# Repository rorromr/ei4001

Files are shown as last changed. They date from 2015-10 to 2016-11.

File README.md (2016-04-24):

# EI4001

## Torso lift mechanism

## Instalación

# Repositorio

```
git clone https://github.com/rorromr/ei4001.git
cd ei4001
git submodule init
git submodule update
```
# Librerías Arduino

Para la instalación de librerías se crean enlaces simbolicos en el directorio `~/Arduino/libraries/`.

```
cd ei4001/arduino
./install.sh

```

## Comandos Git

[Guía rápida Git](http://rogerdudler.github.io/git-guide/index.es.html)

### Commandos útiles

* Clonar repositorio: `git clone user@ip_server:repo`
* Crear rama: `git checkout -b nueva_rama`
* Listar ramas: `git branch -a`
* Bajar rama: `git pull origin nombre_rama`
* Crear rama local y setear track remoto: `git checkout -t origin/nombre_rama`
* Borrar rama local (-D para forzar): `git branch -d nombre_rama`
* Borrar rama remota: `git push origin :nombre-rama`
* Subir nueva rama con tracking: `git push -u origin rama`
* Actualizar lista de ramas: `git remote update origin --prune`
* Borrar rama local: `git branch -d rama`
* Borrar rama remota: `git push origin --delete rama`

## Markdown

* [Markdown basics](https://help.github.com/articles/markdown-basics/)
* [Mastering Markdown](https://guides.github.com/features/mastering-markdown/)

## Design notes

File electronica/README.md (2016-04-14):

# EI4001

## Torso lift mechanism

Archivos de diseño electrónico.

## Puente H

Puente H basado en MOSFET de potencia IRF2804 usando drivers
IR2110.

## Sitios web

* [Calculo de ancho de pistas](http://www.desmith.net/NMdS/Electronics/TraceWidth.html)
* [Ejemplos puente H](http://tahmidmc.blogspot.cl/2013/01/using-high-low-side-driver-ir2110-with.html)

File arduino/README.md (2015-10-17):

# SerialDXL

Librería para el manejo de dispositivos usando el protoco Dynamixel sobre RS485.
Gestiona la recepción de mensajes y mapeo de memoria (RAM e EEPROM).

# Encoder

Librería para el uso de pines digitales por registro [DigitalIO](https://github.com/greiman/DigitalIO/blob/master/DigitalIO/PinIO.h).

# Instalación

* Se debe instalar el software Arduino en `/opt/ardino`.
* Las librerías de usuario se almacenan en `~/Arduino/libraries`.
* Configurar [Ardunino-Makefile](https://github.com/sudar/Arduino-Makefile) según `setup.sh`.

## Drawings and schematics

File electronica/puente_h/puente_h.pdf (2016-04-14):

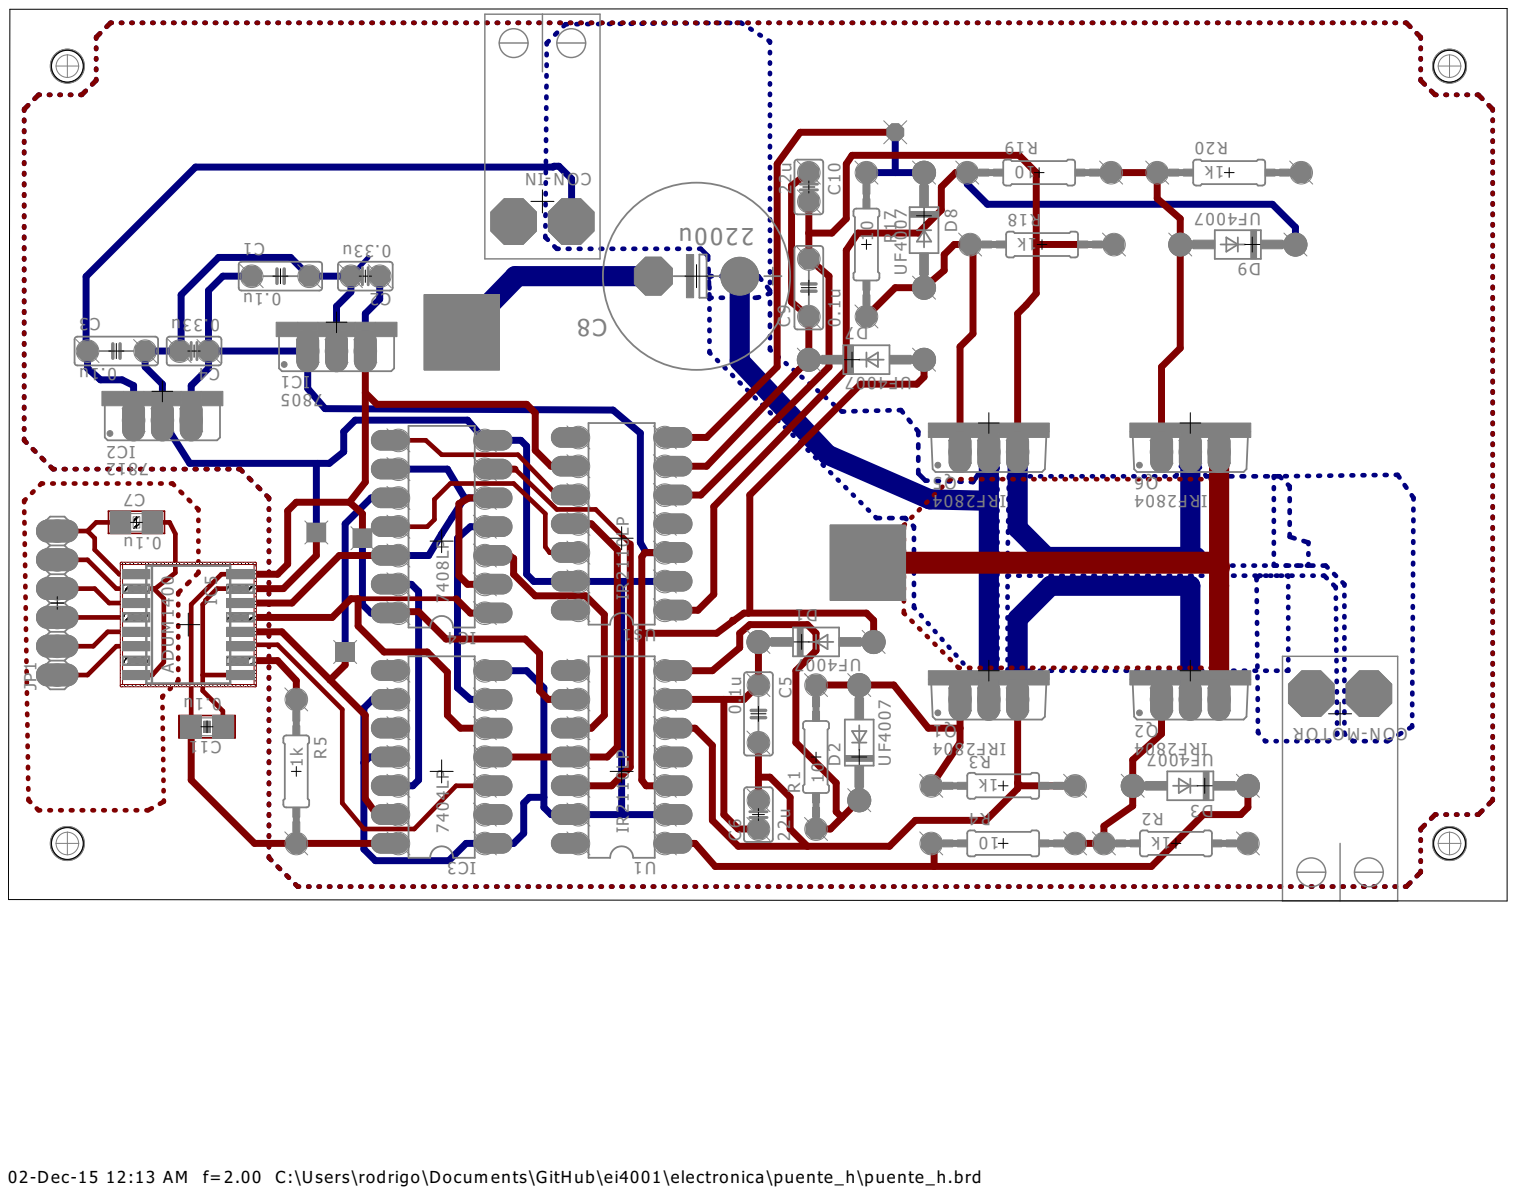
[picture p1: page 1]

02-Dec-15 12:13 AM f=2.00 C:\Users\rodrigo\Documents\GitHub\ei4001\electronica\puente_h\puente_h.brd

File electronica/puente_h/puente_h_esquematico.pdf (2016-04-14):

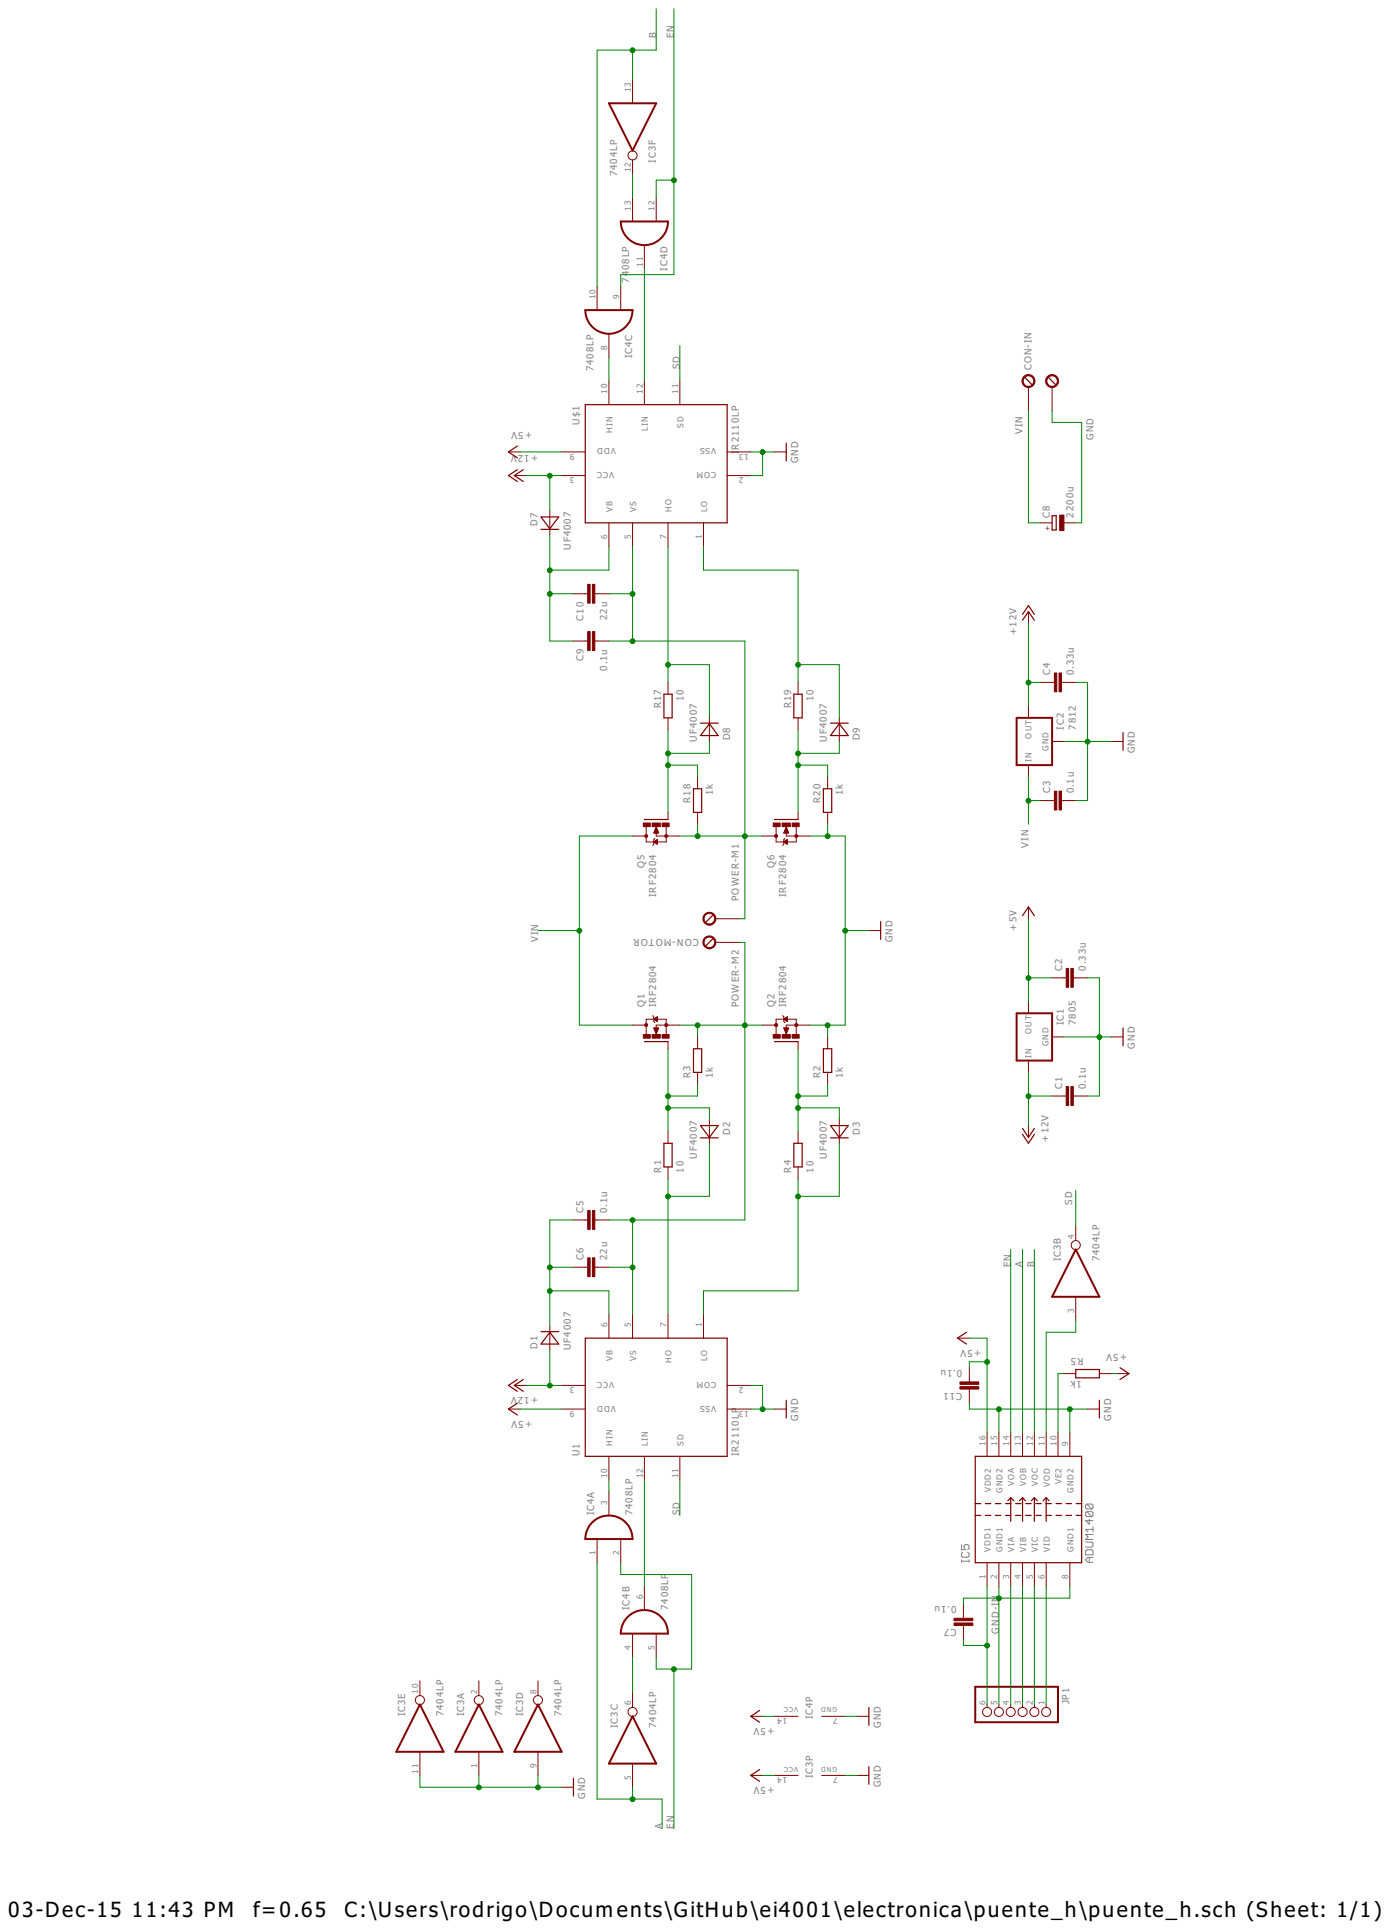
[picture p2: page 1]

03-Dec-15 11:43 PM f=0.65 C:\Users\rodrigo\Documents\GitHub\ei4001\electronica\puente_h\puente_h.sch (Sheet: 1/1)

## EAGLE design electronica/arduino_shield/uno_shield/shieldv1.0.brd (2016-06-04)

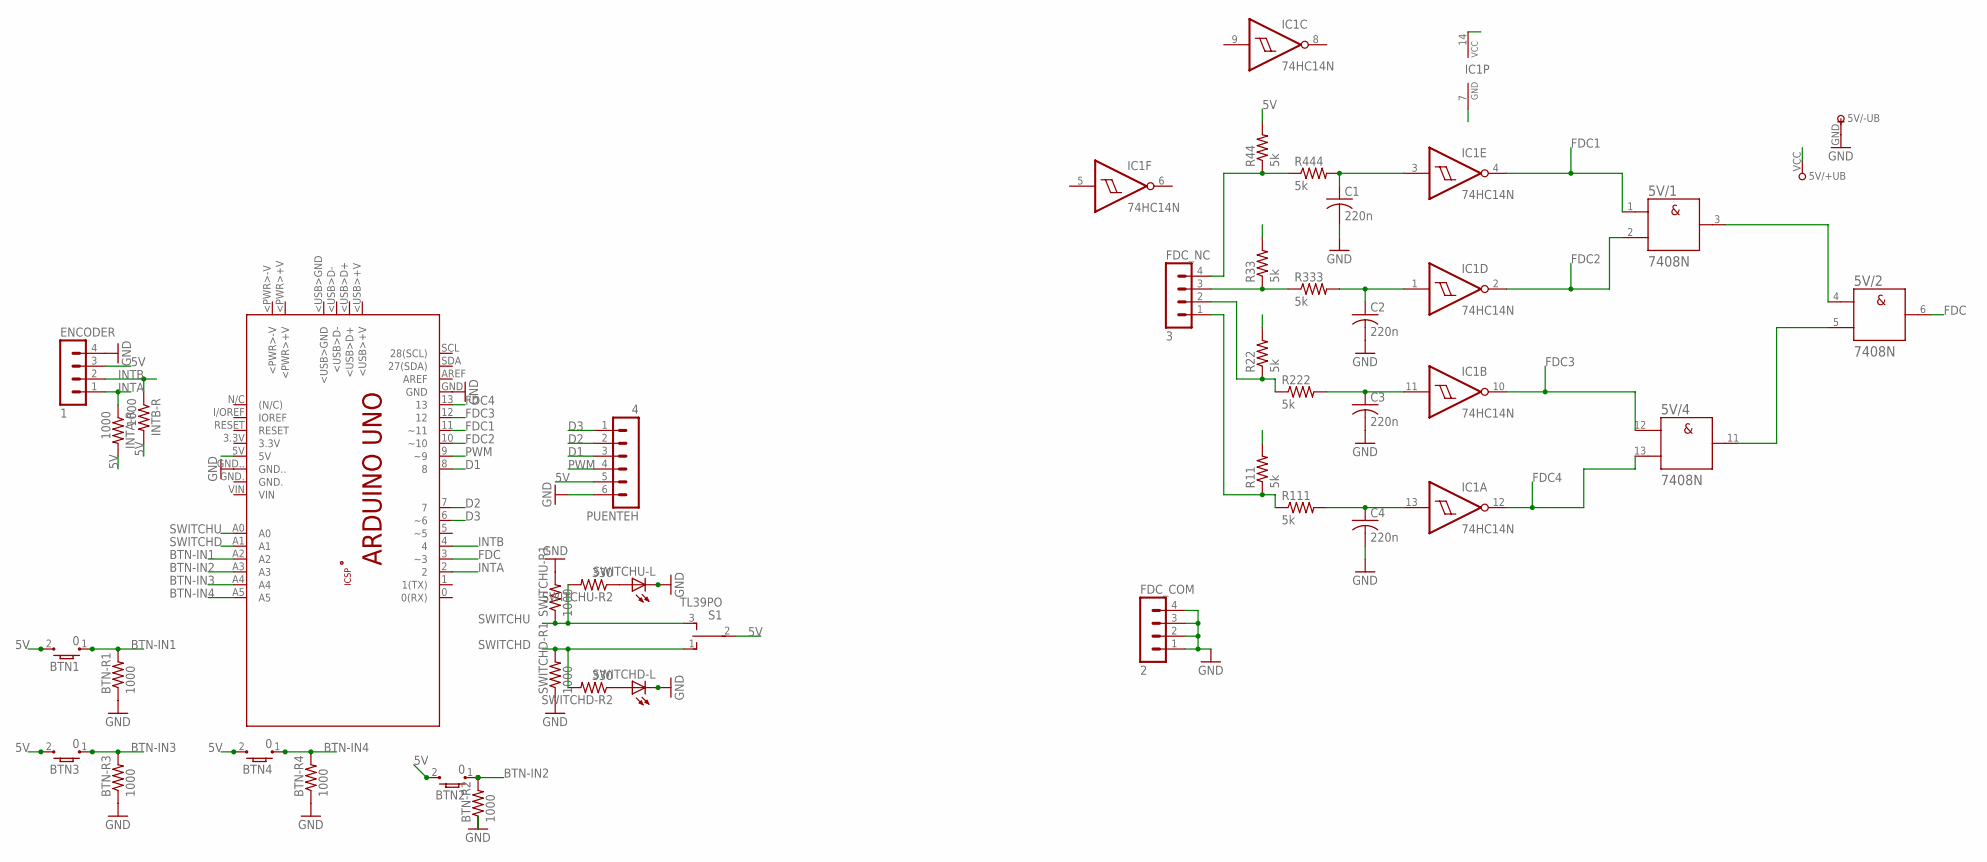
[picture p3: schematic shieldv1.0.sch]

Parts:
5V: 7408N; DIL14
BTN1, BTN2, BTN3, BTN4: 0; TL3303_J
BTN-R1, BTN-R2, BTN-R3, BTN-R4: 1000; 0204/7
C1, C2, C3, C4: 220n; C025-030X050
ENCODER: 1; MA04-1
FDC_COM: 2; MA04-1
FDC_NC: 3; MA04-1
IC1: 74HC14N; DIL14
INTA-R: 1000; 0204/7
INTB-R: 1000; 0204/7
PCB1: ARDUINO_UNO
PUENTEH: 4; MA06-1
R11, R22, R33, R44, R111, R222, R333, R444: 5k; 0204/7
S1: TL39PO; TL3XPO
SWITCHD-L: LED_ELD260; LED_LD260
SWITCHD-R1: 1000; 0204/7
SWITCHD-R2: 330; 0204/7
SWITCHU-L: LED_ELD260; LED_LD260
SWITCHU-R1: 1000; 0204/7
SWITCHU-R2: 330; 0204/7

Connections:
5V: 5V.VCC (+UB), BTN1.2, BTN2.2, BTN3.2, BTN4.2, ENCODER.3, IC1.14 (VCC), INTA-R.2, INTB-R.2, PCB1.5V, PUENTEH.5, R11.2, R22.2, R33.2, R44.2, S1.2
BTN-IN1: BTN1.1, BTN-R1.2, PCB1.A2
BTN-IN2: BTN2.1, BTN-R2.2, PCB1.A3
BTN-IN3: BTN3.1, BTN-R3.2, PCB1.A4
BTN-IN4: BTN4.1, BTN-R4.2, PCB1.A5
D1: PCB1.8, PUENTEH.3
D2: PCB1.7, PUENTEH.2
D3: PCB1.6 (~6), PUENTEH.1
FDC: 5V.6 (Y), PCB1.3 (~3)
FDC1: 5V.1 (A), IC1.4 (O), PCB1.11 (~11)
FDC2: 5V.2 (B), IC1.2 (O), PCB1.10 (~10)
FDC3: 5V.12 (A), IC1.10 (O), PCB1.12
FDC4: 5V.13 (B), IC1.12 (O), PCB1.13
GND: 5V.GND (-UB), BTN-R1.1, BTN-R2.1, BTN-R3.1, BTN-R4.1, C1.2, C2.2, C3.2, C4.2, ENCODER.4, FDC_COM.1, FDC_COM.2, FDC_COM.3, FDC_COM.4, IC1.7 (GND), PCB1.GND, PCB1.GND.., PUENTEH.6, SWITCHD-L.K (C), SWITCHD-R1.1, SWITCHU-L.K (C), SWITCHU-R1.2
INTA: ENCODER.1, INTA-R.1, PCB1.2
INTB: ENCODER.2, INTB-R.1, PCB1.4
unnamed: FDC_NC.3, R33.1, R333.1
unnamed: SWITCHU-L.A, SWITCHU-R2.1
unnamed: SWITCHD-L.A, SWITCHD-R2.1
unnamed: FDC_NC.4, R44.1, R444.1
unnamed: C1.1, IC1.3 (I), R444.2
unnamed: C2.1, IC1.1 (I), R333.2
unnamed: FDC_NC.2, R22.1, R222.1
unnamed: C3.1, IC1.11 (I), R222.2
unnamed: FDC_NC.1, R11.1, R111.1
unnamed: C4.1, IC1.13 (I), R111.2
unnamed: 5V.5 (B), 5V.11 (Y)
unnamed: 5V.3 (Y), 5V.4 (A)
PWM: PCB1.9 (~9), PUENTEH.4
SWITCHD: PCB1.A1, S1.1 (O), SWITCHD-R1.2, SWITCHD-R2.2
SWITCHU: PCB1.A0, S1.3 (S), SWITCHU-R1.1, SWITCHU-R2.2

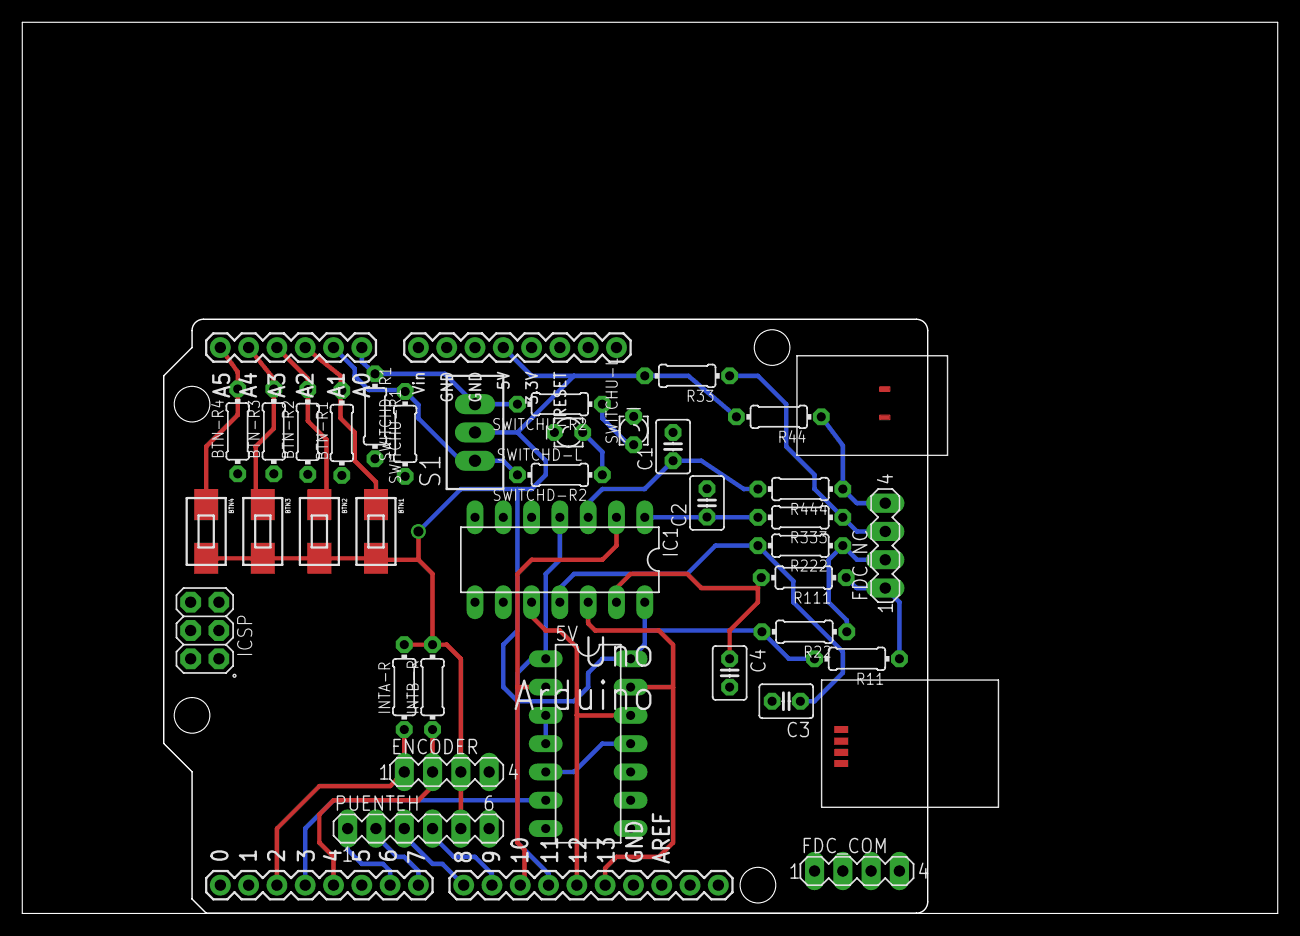
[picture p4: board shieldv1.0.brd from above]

Board: 2 copper layers, 112.7 x 80.0 mm, 36 parts (0 on the bottom side), 31 nets.

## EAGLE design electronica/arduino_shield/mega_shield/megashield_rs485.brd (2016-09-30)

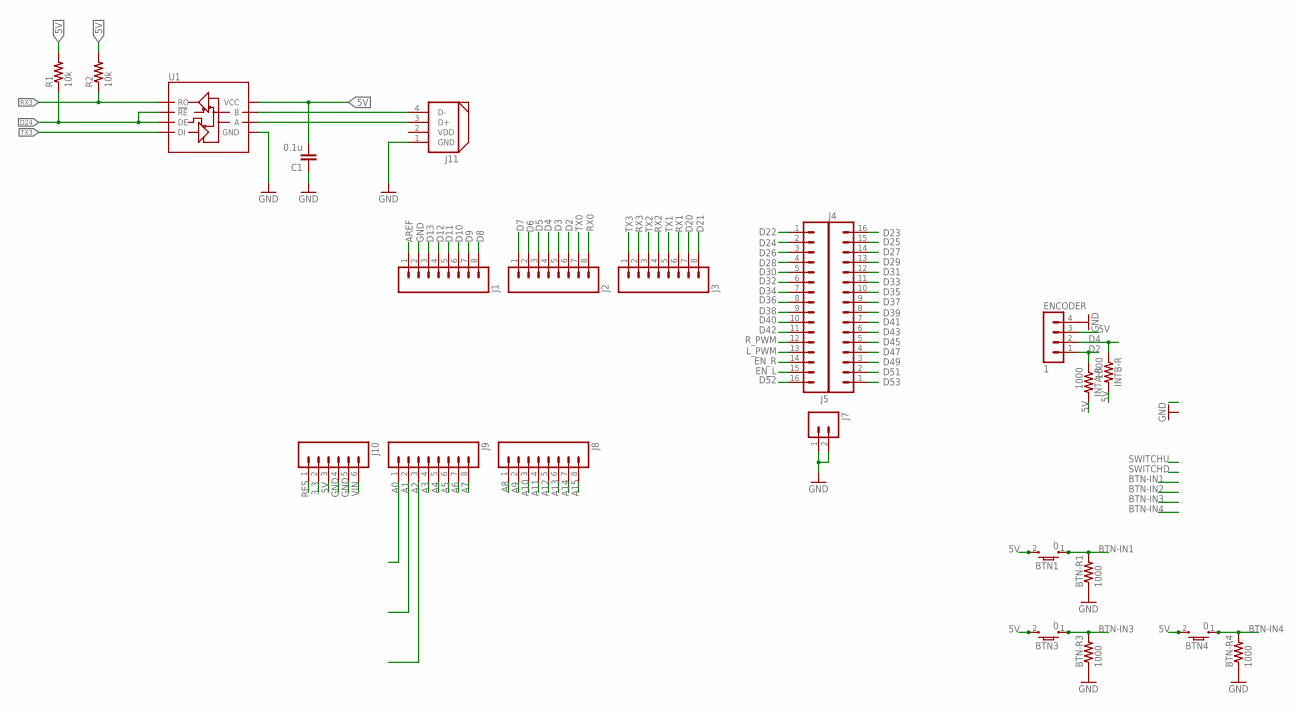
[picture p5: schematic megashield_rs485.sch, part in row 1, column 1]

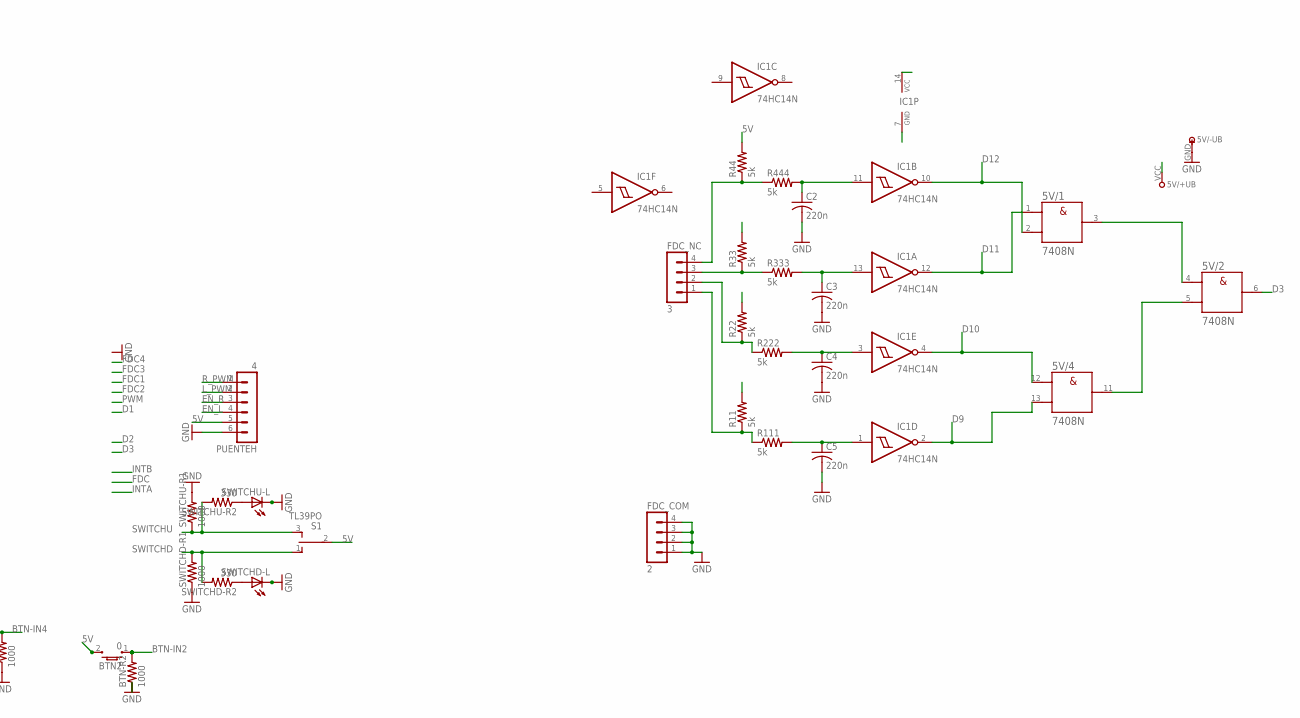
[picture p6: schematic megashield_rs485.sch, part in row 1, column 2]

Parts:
5V: 7408N; DIL14
BTN1, BTN2, BTN3, BTN4: 0; TL3303_J
BTN-R1, BTN-R2, BTN-R3, BTN-R4: 1000; 0204/7
C1: 0.1u; CAP-PTH-SMALL
C2, C3, C4, C5: 220n; C025-030X050
ENCODER: 1; MA04-1
FDC_COM: 2; MA04-1
FDC_NC: 3; MA04-1
IC1: 74HC14N; DIL14
INTA-R: 1000; 0204/7
INTB-R: 1000; 0204/7
J1, J2, J3, J8, J9: M08LONGPADS; 1X08_LONGPADS
J4, J5: M16PTH; 1X16
J7: M02PTH; 1X02
J10: M06LONGPADS; 1X06_LONGPADS
J11: DYNAMIXEL_RS485; DYNAMIXEL_SPOX_04
PUENTEH: 4; MA06-1
R1, R2: 10k; AXIAL-0.4
R11, R22, R33, R44, R111, R222, R333, R444: 5k; 0204/7
S1: TL39PO; TL3XPO
SWITCHD-L: LED_ELD260; LED_LD260
SWITCHD-R1: 1000; 0204/7
SWITCHD-R2: 330; 0204/7
SWITCHU-L: LED_ELD260; LED_LD260
SWITCHU-R1: 1000; 0204/7
SWITCHU-R2: 330; 0204/7
U1: RS485; DIL08

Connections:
3.3: J10.2
5V: 5V.VCC (+UB), BTN1.2, BTN2.2, BTN3.2, BTN4.2, C1.2, ENCODER.3, IC1.14 (VCC), INTA-R.2, INTB-R.2, J10.3, PUENTEH.5, R1.P$2 (2), R2.P$2 (2), R11.2, R22.2, R33.2, R44.2, S1.2, U1.8 (VCC)
A0: J9.1
A1: J9.2
A2: J9.3
A3: J9.4
A4: J9.5
A5: J9.6
A6: J9.7
A7: J9.8
A8: J8.1
A9: J8.2
A10: J8.3
A11: J8.4
A12: J8.5
A13: J8.6
A14: J8.7
A15: J8.8
AREF: J1.1
BTN-IN1: BTN1.1, BTN-R1.2
BTN-IN2: BTN2.1, BTN-R2.2
BTN-IN3: BTN3.1, BTN-R3.2
BTN-IN4: BTN4.1, BTN-R4.2
D2: ENCODER.1, INTA-R.1, J2.6
D3: 5V.6 (Y), J2.5
D4: ENCODER.2, INTB-R.1, J2.4
D5: J2.3
D6: J2.2
D7: J2.1
D8: J1.8
D9: 5V.13 (B), IC1.2 (O), J1.7
D10: 5V.12 (A), IC1.4 (O), J1.6
D11: 5V.1 (A), IC1.12 (O), J1.5
D12: 5V.2 (B), IC1.10 (O), J1.4
D13: J1.3
D20: J3.7
D21: J3.8
D22: J5.1
D23: J4.16
D24: J5.2, R1.P$1 (1), U1.2 (!RE), U1.3 (DE)
D25: J4.15
D26: J5.3
D27: J4.14
D28: J5.4
D29: J4.13
D30: J5.5
D31: J4.12
D32: J5.6
D33: J4.11
D34: J5.7
D35: J4.10
D36: J5.8
D37: J4.9
D38: J5.9
D39: J4.8
D40: J5.10
D41: J4.7
D42: J5.11
D43: J4.6
D45: J4.5
D47: J4.4
D49: J4.3
D51: J4.2
D52: J5.16
D53: J4.1
EN_L: J5.15, PUENTEH.4
EN_R: J5.14, PUENTEH.3
GND: 5V.GND (-UB), BTN-R1.1, BTN-R2.1, BTN-R3.1, BTN-R4.1, C1.1, C2.2, C3.2, C4.2, C5.2, ENCODER.4, FDC_COM.1, FDC_COM.2, FDC_COM.3, FDC_COM.4, IC1.7 (GND), J1.2, J7.1, J7.2, J10.4, J10.5, J11.1 (GND), PUENTEH.6, SWITCHD-L.K (C), SWITCHD-R1.1, SWITCHU-L.K (C), SWITCHU-R1.2, U1.5 (GND)
L_PWM: J5.13, PUENTEH.2
unnamed: J11.3 (D+), U1.6 (A)
unnamed: J11.4 (D-), U1.7 (B)
unnamed: SWITCHU-L.A, SWITCHU-R2.1
unnamed: SWITCHD-L.A, SWITCHD-R2.1
unnamed: FDC_NC.4, R44.1, R444.1
unnamed: FDC_NC.3, R33.1, R333.1
unnamed: C2.1, IC1.11 (I), R444.2
unnamed: C3.1, IC1.13 (I), R333.2
unnamed: FDC_NC.2, R22.1, R222.1
unnamed: C4.1, IC1.3 (I), R222.2
unnamed: FDC_NC.1, R11.1, R111.1
unnamed: C5.1, IC1.1 (I), R111.2
unnamed: 5V.5 (B), 5V.11 (Y)
unnamed: 5V.3 (Y), 5V.4 (A)
RES: J10.1
RX0: J2.8
RX1: J3.6
RX2: J3.4
RX3: J3.2, R2.P$1 (1), U1.1 (RO)
R_PWM: J5.12, PUENTEH.1
SWITCHD: S1.1 (O), SWITCHD-R1.2, SWITCHD-R2.2
SWITCHU: S1.3 (S), SWITCHU-R1.1, SWITCHU-R2.2
TX0: J2.7
TX1: J3.5
TX2: J3.3
TX3: J3.1, U1.4 (DI)
VDD: J11.2 (VDD)
VIN: J10.6

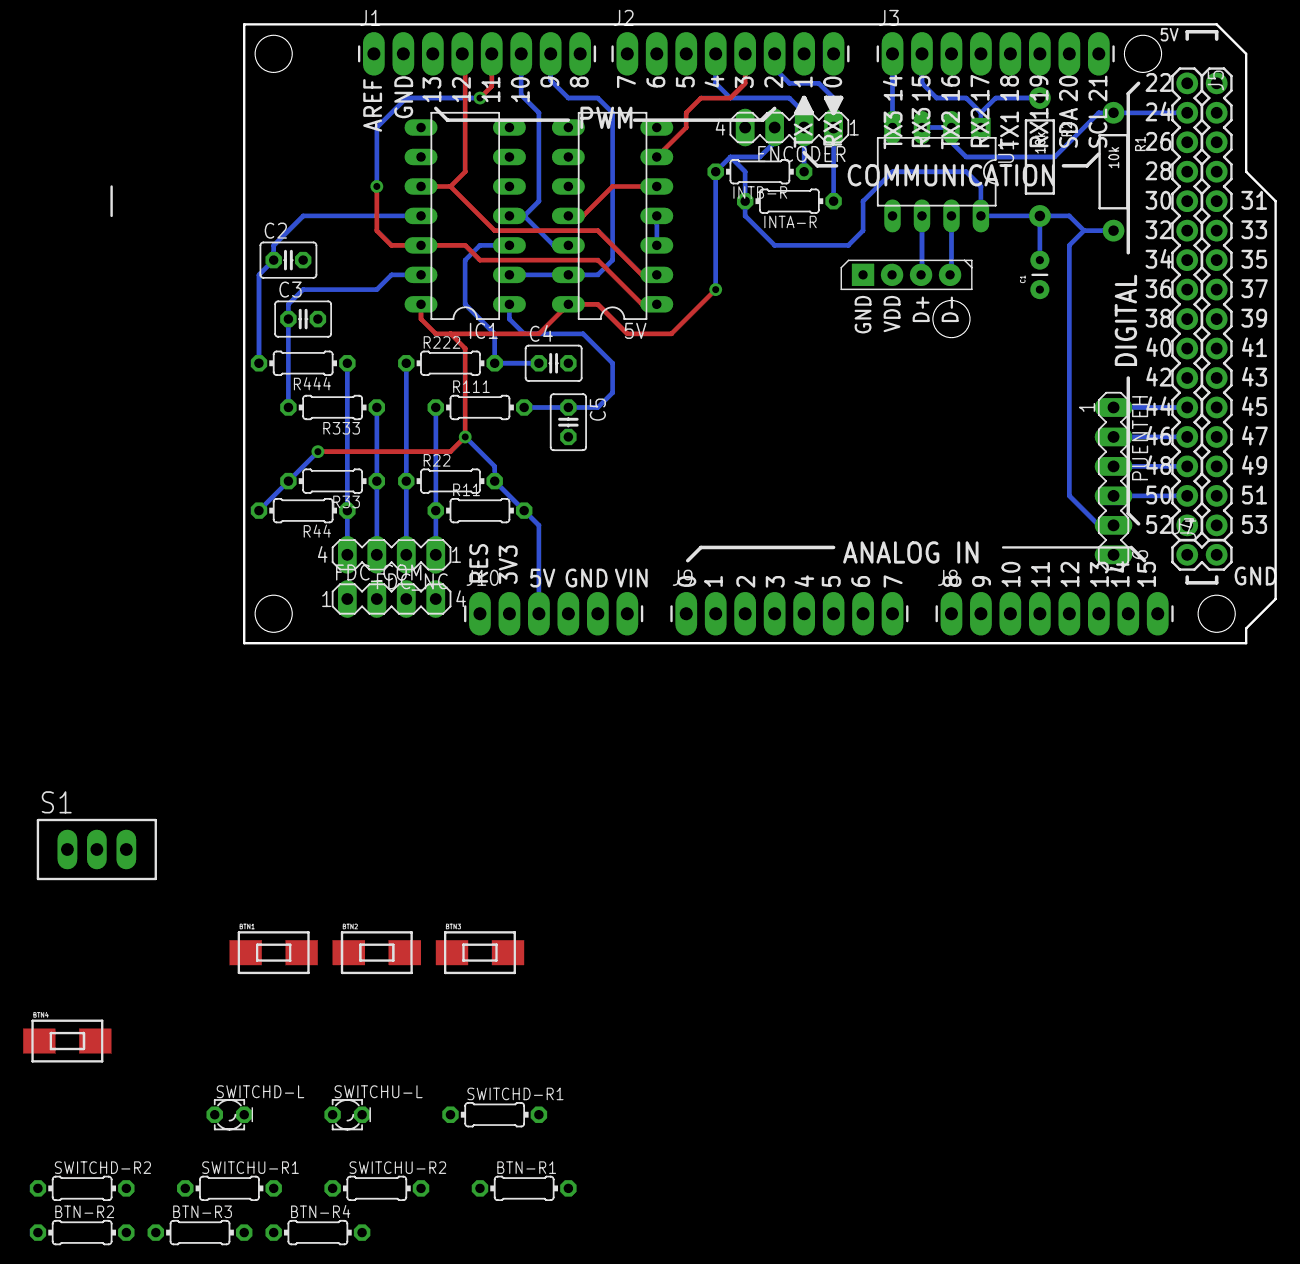
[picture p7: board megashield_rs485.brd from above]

Board: 2 copper layers, 88.9 x 53.3 mm, 49 parts (0 on the bottom side), 36 nets.

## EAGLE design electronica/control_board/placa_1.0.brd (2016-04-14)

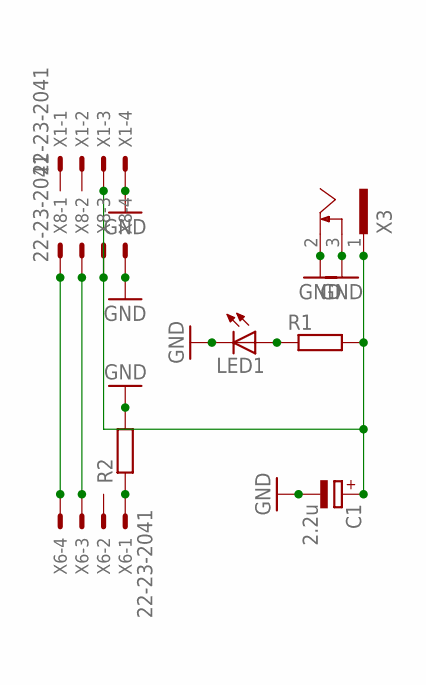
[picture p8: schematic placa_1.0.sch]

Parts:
C1: 2.2u; E5-13
LED1: LED_ELD260; LED_LD260
R1, R2: R0207/10; 0207/10
X1, X6, X8: 22-23-2041
X3: SCD-014A; SCD-014-A

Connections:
GND: C1.-, LED1.K (C), R2.2, X1.4, X3.2, X3.3, X8.4
unnamed: R2.1, X6.1
unnamed: X6.4, X8.1
unnamed: X6.3, X8.2
unnamed: LED1.A, R1.1
VCC: C1.+, R1.2, X1.3, X3.1, X8.3

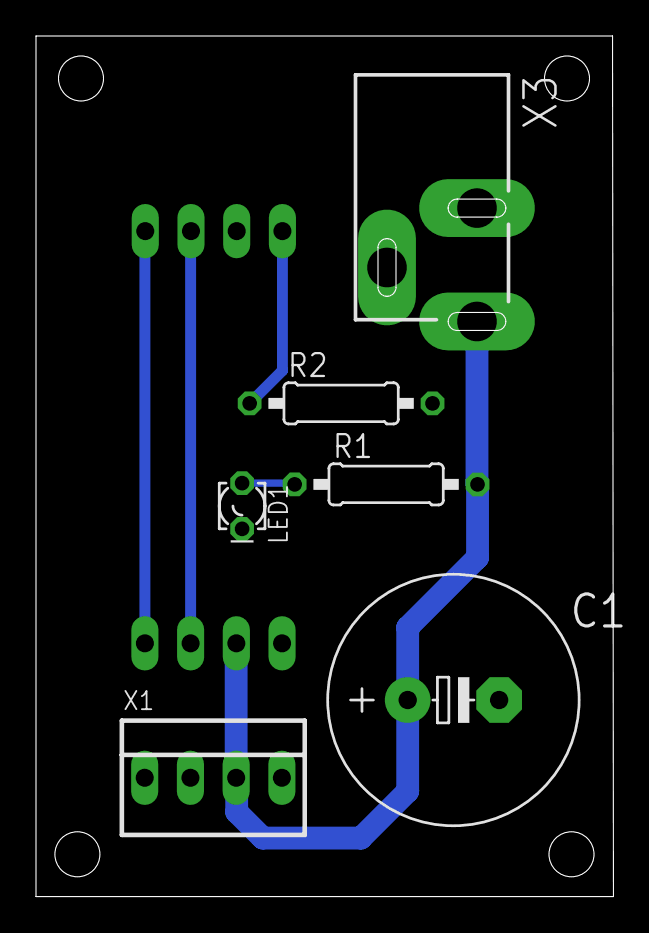
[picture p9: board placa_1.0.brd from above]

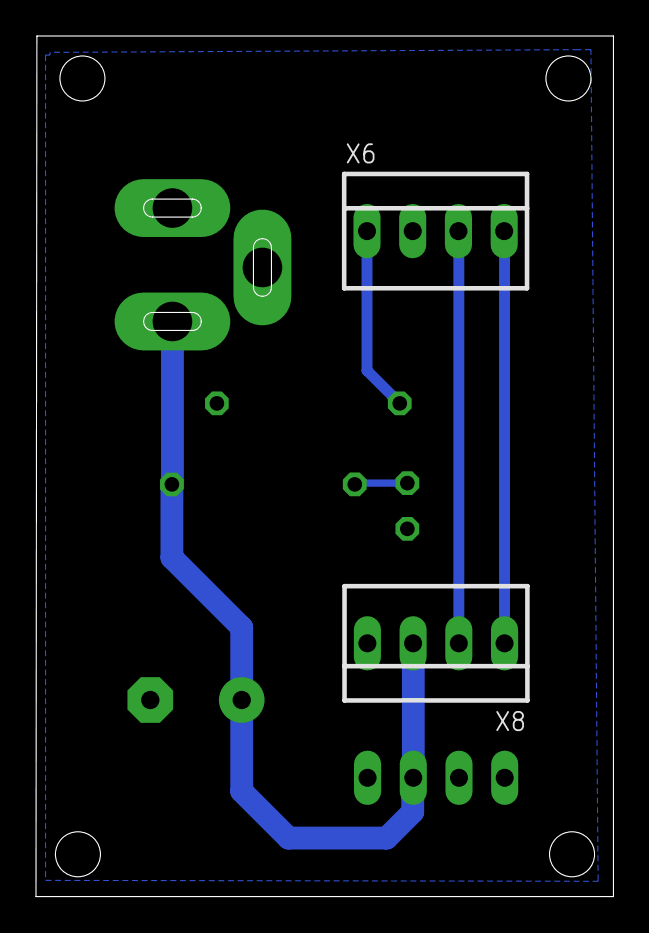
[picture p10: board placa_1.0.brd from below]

Board: 2 copper layers, 32.1 x 47.8 mm, 8 parts (2 on the bottom side), 6 nets.

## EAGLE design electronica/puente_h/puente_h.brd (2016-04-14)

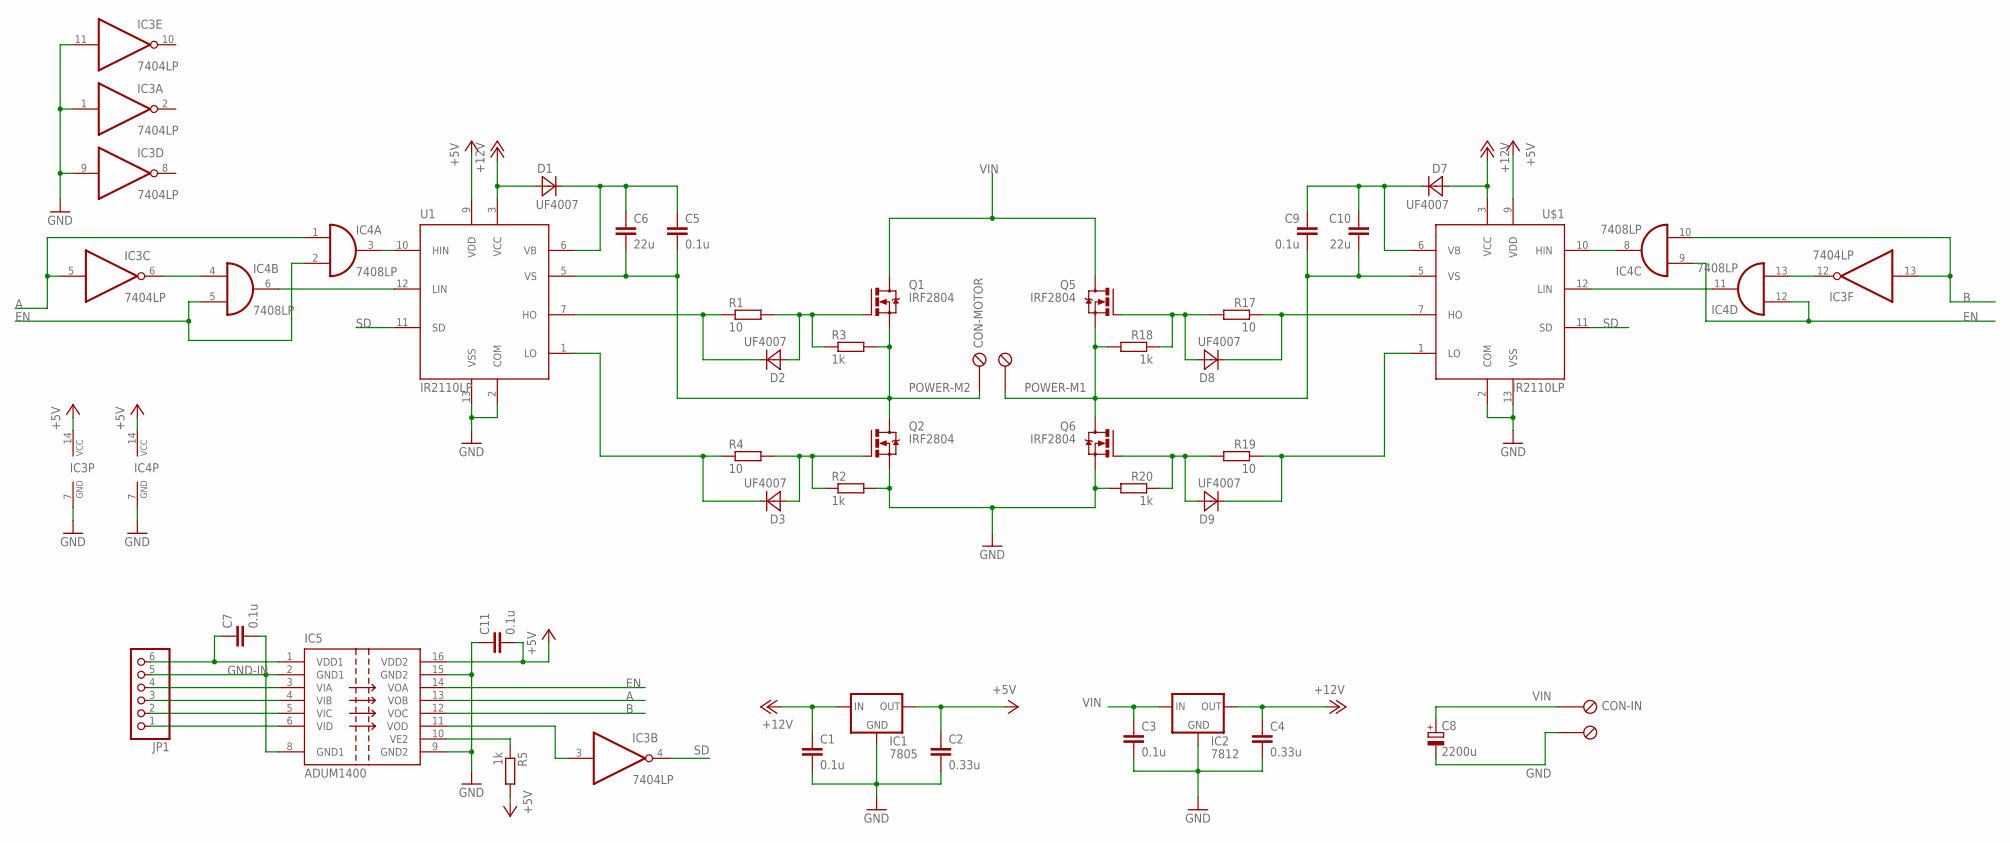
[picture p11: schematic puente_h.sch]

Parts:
C1, C3, C5, C9: 0.1u; C050-025X075
C2, C4: 0.33u; C025-025X050
C6, C10: 22u; C025-025X050
C7, C11: 0.1u; C3216
C8: 2200u; E7,5-16
CON-IN: METALTEX-2
CON-MOTOR: METALTEX-2
D1, D2, D3, D7, D8, D9: UF4007
IC1: 7805; 78XXS
IC2: 7812; 78XXS
IC3: 7404LP; IR2110-LP
IC4: 7408LP; IR2110-LP
IC5: ADUM1400; SO16W
JP1: PINHD-1X6; 1X06
Q1, Q2, Q5, Q6: IRF2804
R1, R4, R17, R19: 10; 0207/12
R2, R3, R5, R18, R20: 1k; 0207/12
U1: IR2110LP; IR2110-LP
U$1: IR2110LP; IR2110-LP

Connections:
+5V: C2.1, C11.2, IC1.OUT, IC3.14 (VCC), IC4.14 (VCC), IC5.16 (VDD2), R5.2, U1.9 (VDD), U$1.9 (VDD)
+12V: C1.1, C4.1, D1.A, D7.A, IC1.IN, IC2.OUT, U1.3 (VCC), U$1.3 (VCC)
A: IC3.5 (I), IC4.1 (I0), IC5.13 (VOB)
B: IC3.13 (I), IC4.10 (I1), IC5.12 (VOC)
EN: IC4.2 (I1), IC4.5 (I1), IC4.9 (I0), IC4.12 (I0), IC5.14 (VOA)
GND: C1.2, C2.2, C3.2, C4.2, C8.-, C11.1, CON-IN.P2, IC1.GND, IC2.GND, IC3.1 (I), IC3.7 (GND), IC3.9 (I), IC3.11 (I), IC4.7 (GND), IC5.9 (GND2), IC5.15 (GND2), Q2.S, Q6.S, R2.2, R20.2, U1.2 (COM), U1.13 (VSS), U$1.2 (COM), U$1.13 (VSS)
GND-IN: C7.2, IC5.2 (GND1), IC5.8 (GND1), JP1.5
unnamed: C5.1, C6.1, D1.C, U1.6 (VB)
unnamed: D2.C, R1.1, U1.7 (HO)
unnamed: D2.A, Q1.G, R1.2, R3.1
unnamed: D3.C, R4.1, U1.1 (LO)
unnamed: D3.A, Q2.G, R2.1, R4.2
unnamed: IC4.8 (O), U$1.10 (HIN)
unnamed: IC3.6 (O), IC4.4 (I0)
unnamed: IC4.3 (O), U1.10 (HIN)
unnamed: IC4.6 (O), U1.12 (LIN)
unnamed: IC5.5 (VIC), JP1.2
unnamed: IC5.10 (VE2), R5.1
unnamed: IC3.12 (O), IC4.13 (I1)
unnamed: IC3.3 (I), IC5.11 (VOD)
unnamed: IC4.11 (O), U$1.12 (LIN)
unnamed: IC5.6 (VID), JP1.1
unnamed: IC5.4 (VIB), JP1.3
unnamed: IC5.3 (VIA), JP1.4
unnamed: C7.1, IC5.1 (VDD1), JP1.6
unnamed: C9.1, C10.1, D7.C, U$1.6 (VB)
unnamed: D8.C, R17.1, U$1.7 (HO)
unnamed: D8.A, Q5.G, R17.2, R18.1
unnamed: D9.C, R19.1, U$1.1 (LO)
unnamed: D9.A, Q6.G, R19.2, R20.1
POWER-M1: C9.2, C10.2, CON-MOTOR.P2, Q5.S, Q6.D, R18.2, U$1.5 (VS)
POWER-M2: C5.2, C6.2, CON-MOTOR.P1, Q1.S, Q2.D, R3.2, U1.5 (VS)
SD: IC3.4 (O), U1.11 (SD), U$1.11 (SD)
VIN: C3.1, C8.+, CON-IN.P1, IC2.IN, Q1.D, Q5.D

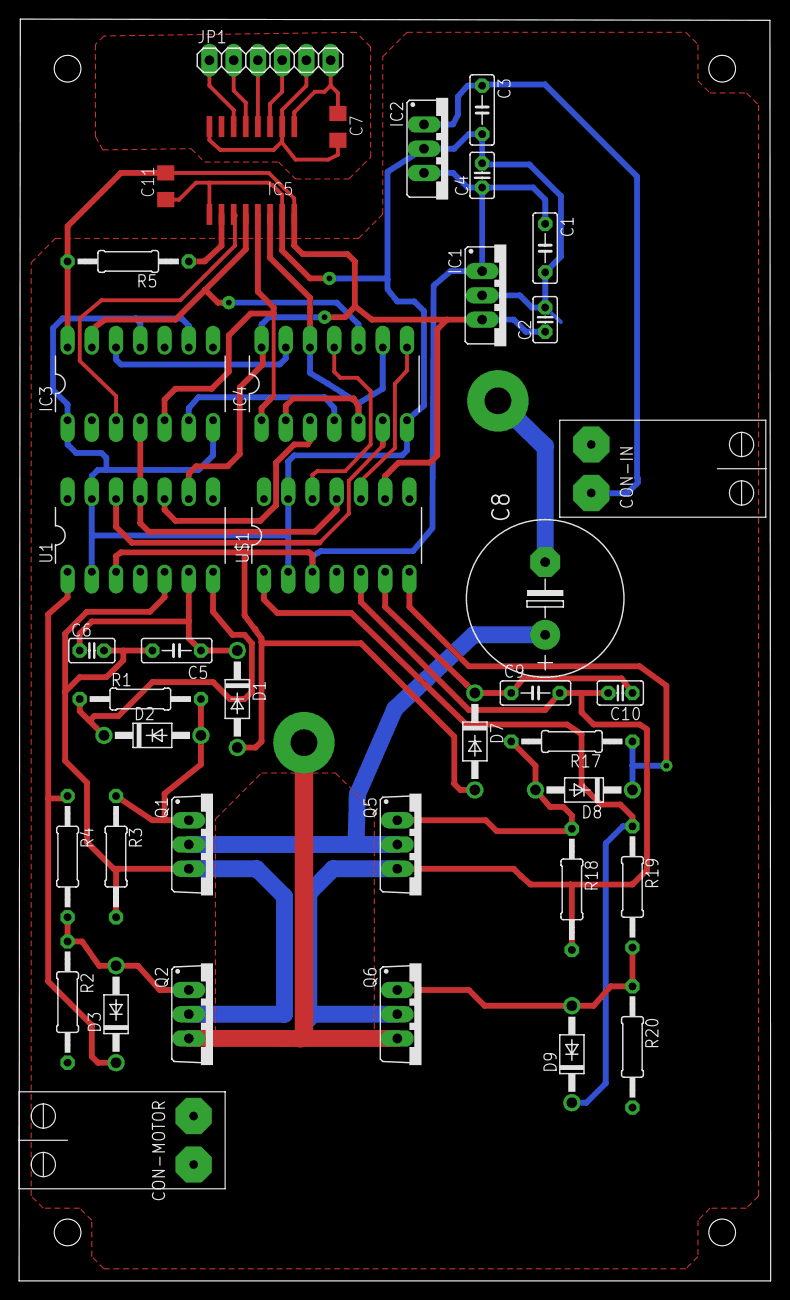
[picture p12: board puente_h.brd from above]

Board: 2 copper layers, 78.7 x 132.2 mm, 40 parts (0 on the bottom side), 34 nets.

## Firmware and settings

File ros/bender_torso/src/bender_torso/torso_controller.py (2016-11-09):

#!/usr/bin/python

__author__ = 'Rodrigo Munoz'

import math
import rospy

from threading import Thread

from std_msgs.msg import Int32

# Use HW interface
from bender_torso.torso_hw import TorsoHW
import numpy as np
import time
import math

class TorsoController:
    def __init__(self, dxl_io, controller_namespace, port_namespace):
        # Only argument stuff
        self.running = False
        self.dxl_io = dxl_io
        self.controller_namespace = controller_namespace
        self.port_namespace = port_namespace
        
    def initialize(self):
        # Get params and allocate msgs
        self.state_update_rate = rospy.get_param(self.controller_namespace + '/rate', 400)
        self.dev_id = rospy.get_param(self.controller_namespace + '/id', 1)
        self.torso = TorsoHW(self.dxl_io, self.dev_id)
        self.state = Int32()
        self.state.data = 0

    def start(self):
        # Create subs, services, publishers, threads
        self.running = True
        self.command_sub = rospy.Subscriber(self.controller_namespace + '/command', Int32, self.process_command)
        self.state_pub = rospy.Publisher(self.controller_namespace + '/state', Int32, queue_size = 5)
        Thread(target=self.update_state).start()

    def stop(self):
        self.running = False
        self.command_sub.unregister()
        self.state_pub.unregister()

    def process_command(self, msg):
        # TODO(rorromr) Add limits
        vel = 5000.0/1.8 # Velocity
        dist = abs(msg.data-self.state.data)
        tf = dist/vel
        segments = int(dist/25)
        data = self.get_parabolic_trajectory(tf=tf, qf=msg.data, q0=self.state.data, segments=segments)
        pos = data[1]
        for point in pos:
            try:
                self.torso.send_position_goal(int(point))
            except Exception:
                rospy.logerr("Error sending position goal.")
            time.sleep(tf/segments)

    def update_state(self):
        rate = rospy.Rate(self.state_update_rate)
        error_count = 0
        while self.running and not rospy.is_shutdown():
            try:
                #self.torso.get_emergency_state()
                # if not self.torso.ping():
                #     raise Exception("Ping fail")
                current_state = self.torso.get_state()
            except Exception:
                error_count += 1
                rospy.logwarn("Error reading state {}.".format(error_count))
                rospy.sleep(0.05)
                continue
            self.state.data = current_state[0]
            # Publish current position
            self.state_pub.publish(self.state)
            rate.sleep()

    def get_parabolic_trajectory(self, tf, qf, qqf=0, q0=0, qq0=0, segments=50):
        # Polynomial coeficients
        a0=q0
        a1=qq0
        a2=(3.0*(qf-q0)-tf*(2*qq0+qqf))/(tf**2)
        a3=(2.0*(q0-qf)+tf*(qq0+qqf))/(tf**3)
        # Time vector
        t=np.linspace(0,tf,segments)
        t2=t*t
        t3=t2*t
        return (t,a0+a1*t+a2*t2+a3*t3, a1+2*a2*t+3*a3*t2, 2*a2+6*a3*t)

if __name__ == '__main__':
    rospy.init_node('led_controller')
    from dynamixel_driver.dynamixel_io import DynamixelIO
    dxl = DynamixelIO('/dev/bender/dxl_test', baudrate=1000000)
    torso = TorsoController(dxl, 'torso', 'torso')
    torso.initialize()
    torso.start()
    rospy.spin()
    torso.stop()
        

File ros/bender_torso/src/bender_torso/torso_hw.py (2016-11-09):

#!/usr/bin/env python
# -*- coding: utf-8 -*-
"""
Low level control for torso hardware using Dynamixel fieldbus protocol.
"""
__author__ = "Rodrigo Muñoz"

import time
from dynamixel_driver.dynamixel_io import DynamixelIO
import struct

class TorsoHW(object):
    """
    Low level control for torso hardware using Dynamixel fieldbus protocol.
    """
    # Memory mapping offsets
    GOAL_POSITION = 6
    MOVING_SPEED = 10
    PRESENT_POSITION = 11
    PRESENT_SPEED = 15
    EMERGENCY_STATE = 16
    LAST_POSITION = 17
    LIMITIS = 21
    PID_KP = 22
    PID_KI = 26
    PID_KV = 30

    def __init__(self, dxl_io, dev_id=1):
        """
        Class for Low level control for torso hardware using Dynamixel fieldbus protocol.
        :param dxl_io: Dynamixel interface.
        :type dxl_io: DynamixelIO
        :param dev_id: Device ID. Must be between 1 and 254.
        :type dev_id: int
        :raise TypeError: If `dxl_io` is not a DynamixelIO.
        """
        # Check arm name
        if not isinstance(dxl_io, DynamixelIO):
            raise TypeError("dxl_io must be a DynamixelIO")
        self.dxl = dxl_io
        self.id = dev_id

    def ping(self):
        """
        Send ping request.
        :raise Exception: if request fail.
        :return: Tuple with ping result and timestamp.
        """
        return self.dxl.ping(self.id)

    def get_state(self):
        """
        Get state of torso.
        :raise Exception: if request fail.
        :return: Tuple with present position, present speed and emergency state.
        """
        # Read memory block
        result = self.dxl.read(self.id, TorsoHW.PRESENT_POSITION, 6)
        raw_data = result[5:-2]
        bin_data = struct.pack('B'*len(raw_data), *raw_data)
        # int32, int8, uint8
        return struct.unpack('<ibB', bin_data)

    def get_emergency_state(self):
        """
        Get emergency state of torso.
        :raise Exception: if request fail.
        :return: Tuple with present position, present speed and emergency state.
        """
        # Read memory block
        result = self.dxl.read(self.id, TorsoHW.EMERGENCY_STATE, 1)
        return result[5:-2][0]

    def send_position_goal(self, position=0):
        """
        Send position goal.
        :raise Exception: if request fail.
        :return: Tuple with the response.
        """
        return self.dxl.write(self.id, TorsoHW.GOAL_POSITION, TorsoHW.serialize_int32(position))

    @staticmethod
    def serialize_int32(data):
        """
        Serialize int32 datatype into byte list.
        :return: Byte list.
        """
        return  [ord(a) for a in list(struct.pack('<l', int(data)))]

    @staticmethod
    def deserialize_int32(data):
        """
        Deserialize int32 datatype from byte list.
        :return: Integer obtained from list.
        """
        data_bin = struct.pack('B'*len(data), *data)
        return struct.unpack('<l', data_bin)[0]


if __name__ == '__main__':
    dxl = DynamixelIO('/dev/bender/dxl_test', baudrate=1000000)
    torso = TorsoHW(dxl, dev_id=1)
    goal = 0
    while True:
        goal += 1000
        torso.send_position_goal(goal)
        for i in range(20):
            print torso.get_state()
            time.sleep(0.1)

    #torso.send_position_goal(500)

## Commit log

2015-09-29 libreria arduino compatible
2015-10-09 debug print usando macros
2015-10-15 test encoder
2015-10-19 device dxl en serial
2015-10-19 serial interrupt
2015-10-20 pid library
2015-10-31 mejoras para rs485
2015-11-02 motor con pid
2015-11-03 algoritmos pid tue
2015-11-06 esquematico puente h
    [puente_h.sch]
2015-11-09 test viernes, esquematico con nuevo optoacoplador
    [puente_h.brd, puente_h.sch]
2015-11-09 pads mas largos
    [puente_h.brd, puente_h.sch]
2015-11-10 packages con pad mas largos, nuevo pcb
    [puente_h.brd, puente_h.sch]
2015-11-10 mejores posiciones
    [puente_h.brd]
2015-11-13 ruteo mejorado
    [puente_h.brd]
2015-11-15 ruteo con poligonos
    [puente_h.brd, puente_h.sch]
2015-11-16 goal generator
    [GoalGenerator.cfg]
2015-11-16 puente h ok
    [puente_h.brd]
2015-11-16 placas nuevas
    [placa_1.0.brd, placa_1.0.sch, puente_h.brd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]
2015-11-17 casi encoder
2015-11-17 conectores puente h
    [puente_h.brd]
2015-11-17 mejoras encoder lib
2015-11-17 encoder 1 ISR
2015-11-17 encoder lib ok
2015-11-18 shield arduino terminado
    [untitled.brd, untitled.sch]
2015-11-22 correccion de planos, adicion de potenciometro
    [untitled.brd, untitled.sch]
2015-11-25 msg a bender_torso, script para actualizar librerias de ros_lib
2015-11-26 EEPROM y timers
2015-12-02 diagrama para verificar puente h
2015-12-04 actualizacion de esquematico
    [puente_h.sch]
2015-12-15 fin de carrera, calibracion, dead zone
2015-12-24 funcion set y mensajes de debug
2015-12-28 deadzone, pwm en libreria puente H
2015-12-29 botones para cambiar referencia
2015-12-29 test completo
    [GoalGenerator.cfg]
2016-01-05 libreria pid con tipo de datos variable
2016-03-29 Serial ISR para Arduino Mega
2016-03-30 arduino mega registers
2016-04-13 LED test on Arduino Mega
2016-04-21 Led test
2016-04-22 Led example with rs485
2016-04-22 LED state machine fix
    [Led.ino]
2016-04-23 Test LED controller with ROS
2016-04-23 LED exmaple
2016-04-27 test fin de carrera
2016-06-08 calibracion y avance de maquina estado
2016-09-07 Inicio de dinamixalizacion de Torso
2016-09-07 no me dejo subirlo al git de SerialDXL, asi que aca va con FLoat32
2016-09-13 mapeo completo, timer para llamar funcion update
2016-09-15 Mejora en estado de emergencia
2016-09-28 Add LedTimer test
2016-09-30 placa mega
    [megashield_rs485.brd, megashield_rs485.sch, shieldv1.0.brd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]
2016-09-30 Fix timmer on Led test
    [LedTimer.ino]
2016-10-06 Fix control table, high level interface
    [TorsoController.ino, torso_controller.py, torso_hw.py]
2016-10-19 PID gains, PWM frequency
2016-11-09 Encoder test at 6KHz
2016-11-09 Stres test on comunication and encoder
